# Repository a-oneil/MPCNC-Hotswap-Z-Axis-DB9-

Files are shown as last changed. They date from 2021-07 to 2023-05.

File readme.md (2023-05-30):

# MPCNC Hotswap Z axis
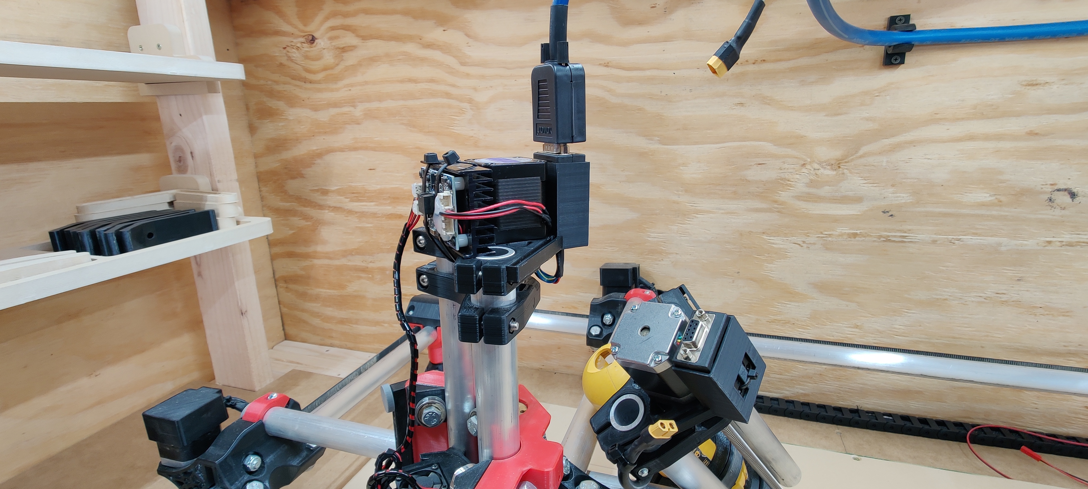
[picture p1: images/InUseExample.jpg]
MPCNC DB9


## Description
**WARNING: KILL POWER TO MPCNC WHEN CONNECTING OR DISCONNECTING ANY WIRES FROM THE MACHINE**

Since adding a laser Z-axis to my MPCNC toolkit, I was looking for a quick way to swap between my CNC and laser Z-axis. I originally had all of the wires with separate connectors to make it hot-swappable and I ended up breaking a few wires at the connector due to the movement of the Z-axis.

After a few trial and error attempts, I ended up designing a new motor mount for the Z-axis to hold a DB9 connector with all the supporting wires for swapping Z-axis assemblies with ease.

Most of the weight of the cable is being held up via retractable badge ID holders which doesn’t add unnecessary strain to the Z-axis core.

[This modification pairs very well with my MPCNC Tornado dust collection/air assist setup!](https://austinoneil.com/mpcnc-tornado/)

## Files
* motor_mount_db9.stl - Motor mount with DB9 connector  
* motor_mount_cable_management.stl - Updated motor mount with zip tie rails for connectors if you don't want to use a DB9Plug  

## Parts
* [x1 Retractable ID Badge Holder](https://www.amazon.com/gp/product/B01N5DW69F/ref=ppx_yo_dt_b_asin_title_o00_s00?ie=UTF8&psc=1)
* [20ft 18 AWG Multi 9 Conductor Blue Speed Wire 18 Gauge Copper Stranded Cable](https://www.amazon.com/gp/product/B083ZKGN5L/ref%3Dppx_yo_dt_b_asin_image_o00_s00?ie=UTF8&psc=1) 
* [1 inch (Diameter) 3:1 Waterproof Heat Shrink Tubing Kit](https://www.amazon.com/gp/product/B07VQ6X5KT/ref%3Dppx_yo_dt_b_asin_title_o01_s01?ie=UTF8&psc=1)
* [x2 Female DB9 RS232 D-Sub Serial Connectors](https://www.amazon.com/gp/product/B076F6X8WJ/ref%3Dppx_yo_dt_b_asin_title_o01_s00?ie=UTF8&psc=1)
* [x1 Male DB9 RS232 D-Sub Serial Connector](https://www.amazon.com/gp/product/B071DS5GTW/ref%3Dppx_yo_dt_b_asin_title_o01_s01?ie=UTF8&psc=1)

# Cable Pinout
Note: These are the correct wire colors for my Z motor and laser assembly. Your mileage may vary. Double-check all wiring before applying power!

| # | Umbilical Cable: | Laser Head: | CNC Head:  |
|---|---|---|---|
| 1 | Z-Motor: Black  | Z-Motor: Black | Z-Motor: Blue  |
| 2 | Z-Motor: Green  | Z-Motor: Green | Z-Motor: Yellow |
| 3 | Z-Motor: Blue | Z-Motor: Blue | Z-Motor: Green |
| 4 | Z-Motor: Red | Z-Motor: Red | Z-Motor: Red |
| 5 | Laser: 5V Signal Pin (Purple)  | Laser: 5V Signal Pin  | Empty  |
| 6 | Laser: Ground (Yellow)  | Laser: Ground  | Empty  |
| 7 | Laser: 12v+ (White)  | Laser: 12v+  | Empty  |
| 8 | Buck Converter –  | Empty  | Empty  |
| 9 | Buck Converter +  | Empty  | Empty  |

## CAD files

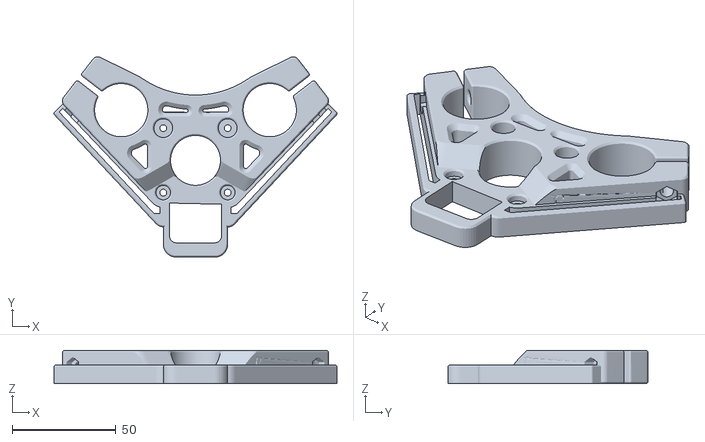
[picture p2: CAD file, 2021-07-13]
motor_mount_cable_management.stl
136.1 x 96.4 x 16.0

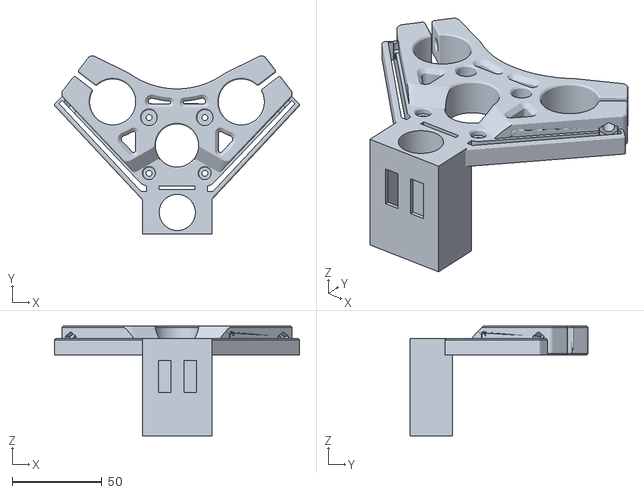
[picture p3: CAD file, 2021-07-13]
motor_mount_db9.stl
136.1 x 99.1 x 61.0

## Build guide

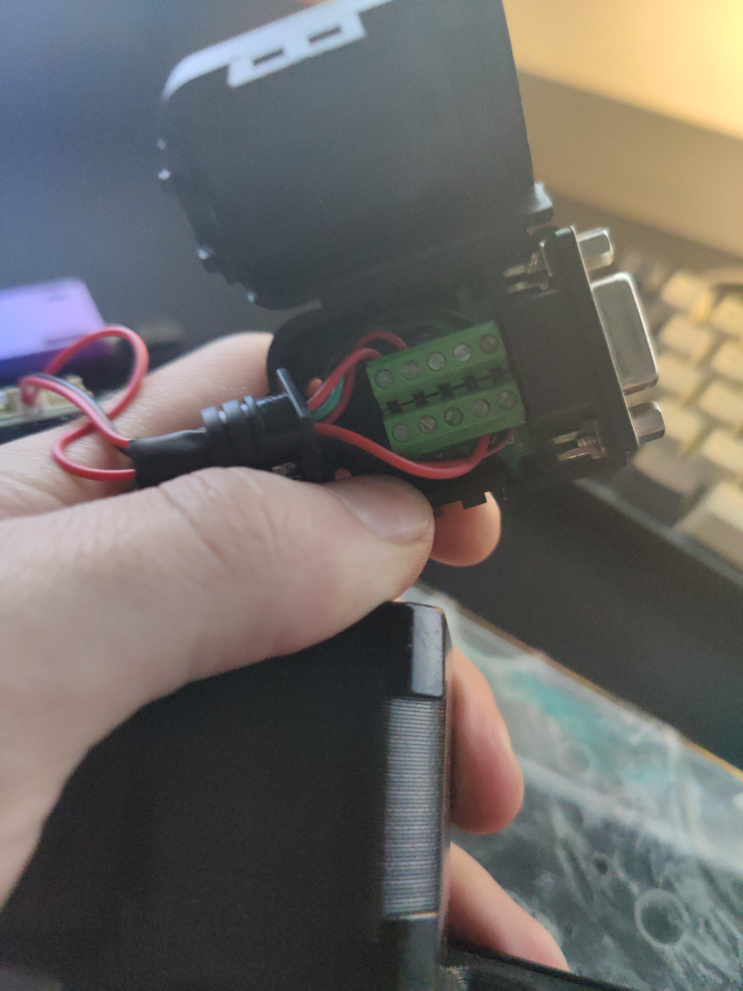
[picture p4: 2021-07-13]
images/DB9_Wiring.jpg

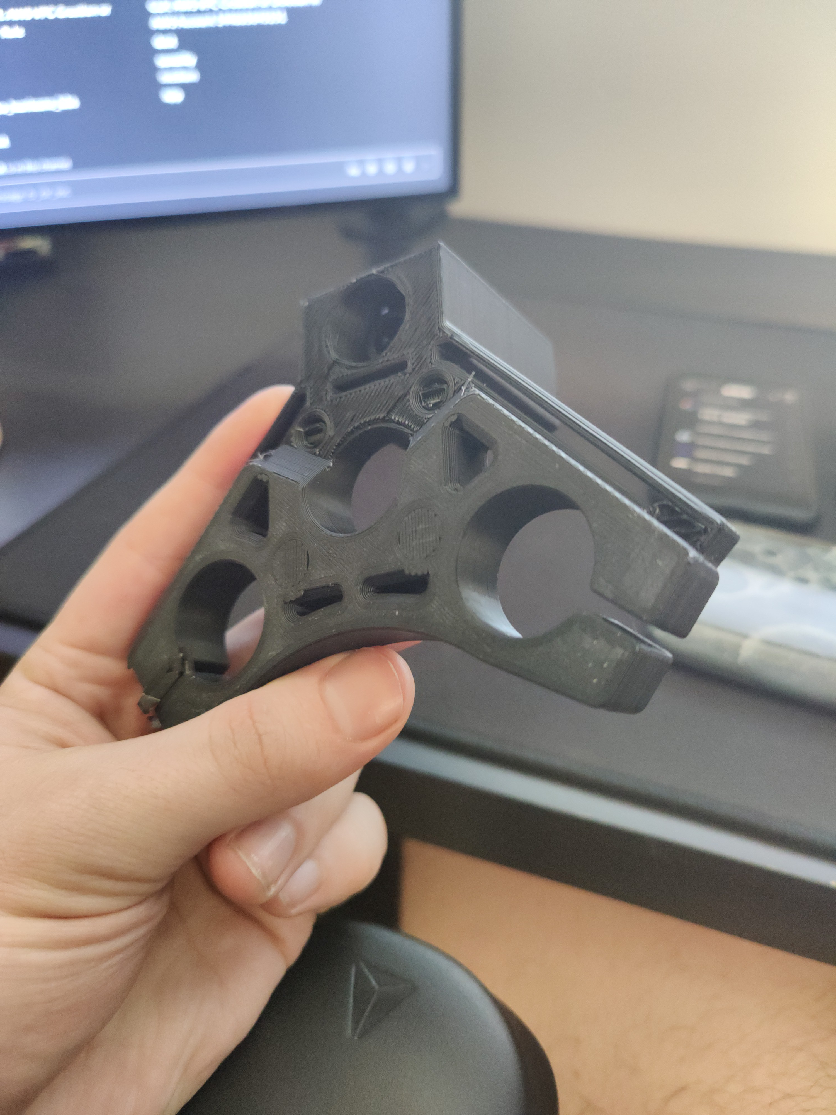
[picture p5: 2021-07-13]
images/PrintedMount.jpg

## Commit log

2021-07-13 Update DB9 Plug.stl, MotorMount.stl, DB9_Wiring.jpg, PrintedMount.jpg, InUseExample.jpg files
    [DB9 Plug.stl, MotorMount.stl]
2023-03-12 repo cleanup
    [motor_mount_cable_management.stl, motor_mount_db9.stl]
